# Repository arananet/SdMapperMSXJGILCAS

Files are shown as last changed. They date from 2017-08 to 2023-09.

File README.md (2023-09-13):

# SD Mapper/Megaram 512K para MSX version @jgilcas

Este cartucho desarrollado por Fabio Belavenuto  (https://github.com/fbelavenuto/msxsdmapper) permite disponer de un dispositivo de carga en el MSX a través de una microSD así como también asignar 512k de memoria RAM al ordenador.

Esta versión se ha modificado para disponer de un solo socket SD, donde su formato ya no es SD sino MicroSD. También se han cambiado las huellas de algunos componentes para facilitar la labor de soldadura.

Se incluye el esquema y los ficheros gerbers para fabricarlo.

If you like the project or want to support it, you can buy me a beer or a KO-FI :) 


# Imagen

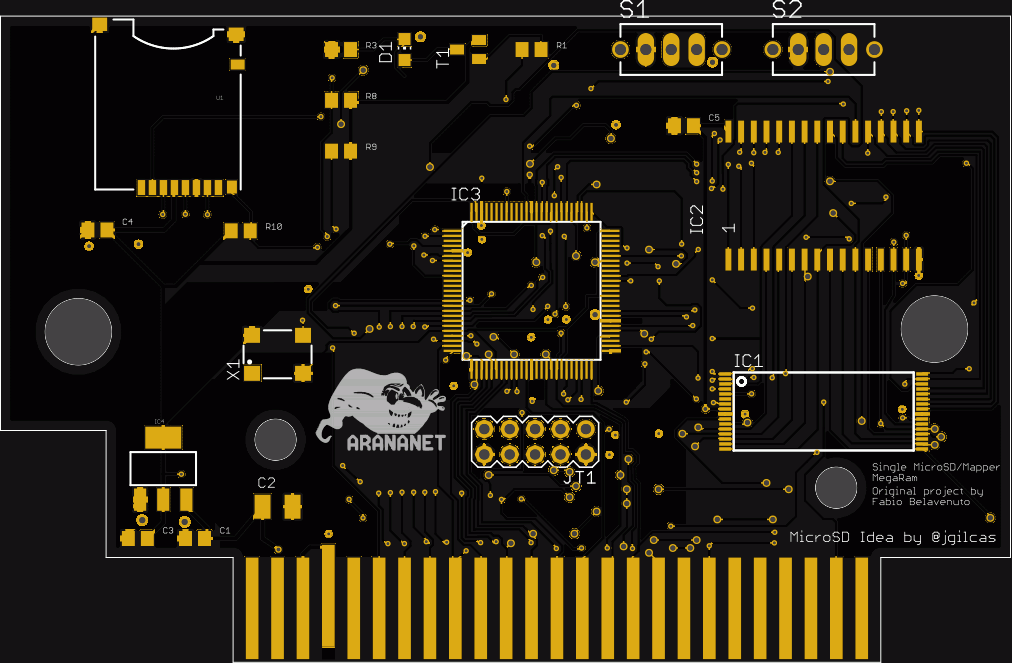
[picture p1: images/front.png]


# Pinout

1-TCK
2-GND
3-TDO
4-VCC
5-TMS
6-NC
7-NC
8-NC
9-TDI
10-GND

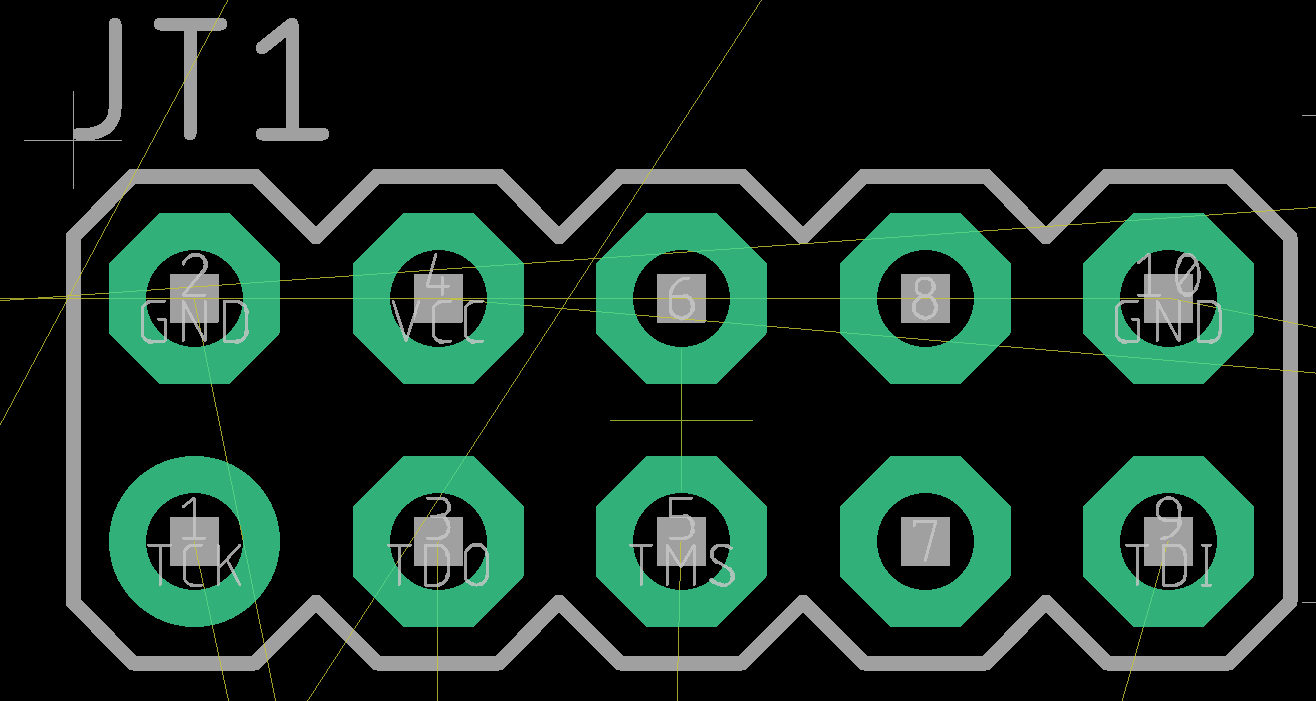
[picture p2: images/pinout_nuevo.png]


# Updates

13/09/2023: Añadido pinout de programación.
05/08/2017: Version inicial del PCB.

# License

https://ohwr.org/cernohl

Copyright (c) 2014 - Fabio Belavenuto

Copyright (c) 2017 - @Edu_Arana

# Lista de materiales

| Part | Value | Package |
| --- | --- | --- |
|  C1 | 100n | C0805 |
|  C2 | 100uf | C0805 |
|  C3 | 100n | C0805 |
|  C4 | 100n | C0805 |
|  C5 | 100n | C0805 |
|  C6 | 100n | C1206 |
|  C7 | 100n | C1206 |
|  D1 | Cart1 | CHIP-LED0805 |
|  IC1 | AM29F010E | TSOP32 |
|  IC2 | HM628512ASOP32 | SOP32 |
|  IC3 | XC95144XL_TQ100 | XC-TQ100 |
|  IC4 | LM1117-3V3 | SOT223 |
|  JP1 | MSXCART1 | MSXCART |
|  JT1 | | PH5X2 |
|  R1 | 4K7 | R0805 |
|  R3 | 330 | R0805 |
|  R8 | 4K7 | R0805 |
|  R9 | 4K7 | R0805 |
|  R10 | 4K7 | R0805 |
|  S1 | TL32YO | TL3XYO |
|  S2 | TL32YO | TL3XYO |
|  T1 | BC858 | SOT23-BEC |
|  U1 | USD-SOCKETUSD | USD-SOCKET-PP |
|  X1 | 25MHz | 7X5 OSCILLATOR |

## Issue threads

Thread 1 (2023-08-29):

Pinout of the JT1...

amazingcobrazil, 2023-08-29:
Hello, I found the version of your board very interesting and I assembled some for my use. The problem is that I can't program any of them with iMPACT. I did not find any information about this version of yours and about anyone who has already built one. Could you tell me the correct pinout of the JT1?
I've currently been using a DLC10 and the following combination on JT1:
[TDI] [___] [TMS] [TDO] [TCK]
[___] [___] [___] [VCC] [GND]
(Looking from the front and above the board connector)

arananet, 2023-09-13:
I've added the pinout. Remember that you can always check the design via EaglePCB.

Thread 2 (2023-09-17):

Write Protect Disk Writing

amazingcobrazil, 2023-09-17:
I managed to get the interface working. The problem I found on the 3 cards assembled is that apparently there is some write protection on the MicroSD card (Write Protect Disk Writing). The error does not happen when I insert this same card into another interface I have (Fabio Belavenuto's SDMapper v2). When I run SofaRun it hangs on the screen: Saving SofaRun Settings. I used version 1.06 of Fábio's repository (https://github.com/fbelavenuto/msxsdmapper) to flash and I also tried version 1.04 as a downgrade. In your tests, which version were you successful in?

arananet, 2023-09-18:
But writable is mandated by the firmware, its true that the write protect is connected, is connect with a pullup to vcc by the resistors. You could try two things, one is to remove the pullup R5 and R7, and the worst one is just to cut the trace or leave the pin WP unconnected from the sockets.

amazingcobrazil, 2023-09-25:
Siento que no me expresé correctamente. No puedo escribir en la MicroSD de su tarjeta de proyecto. Probé en 3 tarjetas idénticas que construí y en varias tarjetas MicroSD, en ninguna pude escribir nada (ni siquiera formatear usando _Fdisk).
